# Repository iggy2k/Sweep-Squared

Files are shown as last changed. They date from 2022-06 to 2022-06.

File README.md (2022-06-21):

# Sweep Squared
 A unibody version of the Ferris Sweep split keyboard.
 
## Why?
The only reason I gave up on using the original Sweep is being able to comfortably use it on top of the laptop keyboard. Hopefully this one will work better.
upd 06/21/2022: it does actually feel better!

## But it's just Zaphod
Yes. 

## Pics
<p align="center">
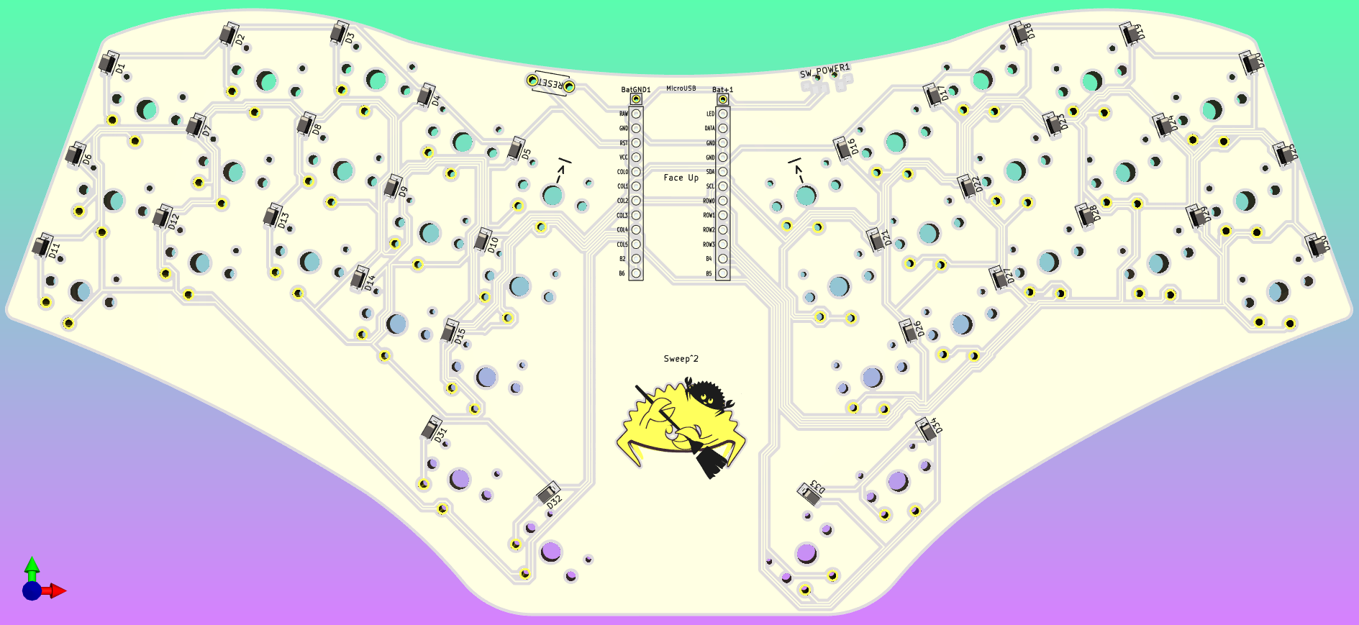
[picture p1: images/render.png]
  
</p>

## Firmware
https://github.com/iggy2k/zmk-squared
 
## Credits
Original Ferris is made by [pierrechevalier83](https://github.com/pierrechevalier83)

Ferris Sweep made by [davidphilipbarr](https://github.com/davidphilipbarr)

Symbols and footprints are credited below.

## Symbols and Footprints
Sources:

https://github.com/foostan/kbd

https://github.com/davidphilipbarr/Kicad-Footprints

https://github.com/ai03-2725/random-keyboard-parts.pretty

https://github.com/Biacco42/ProMicroKiCad

#### Also
ai03 pcb guide is super cool as well as ppl from the keeb discords.

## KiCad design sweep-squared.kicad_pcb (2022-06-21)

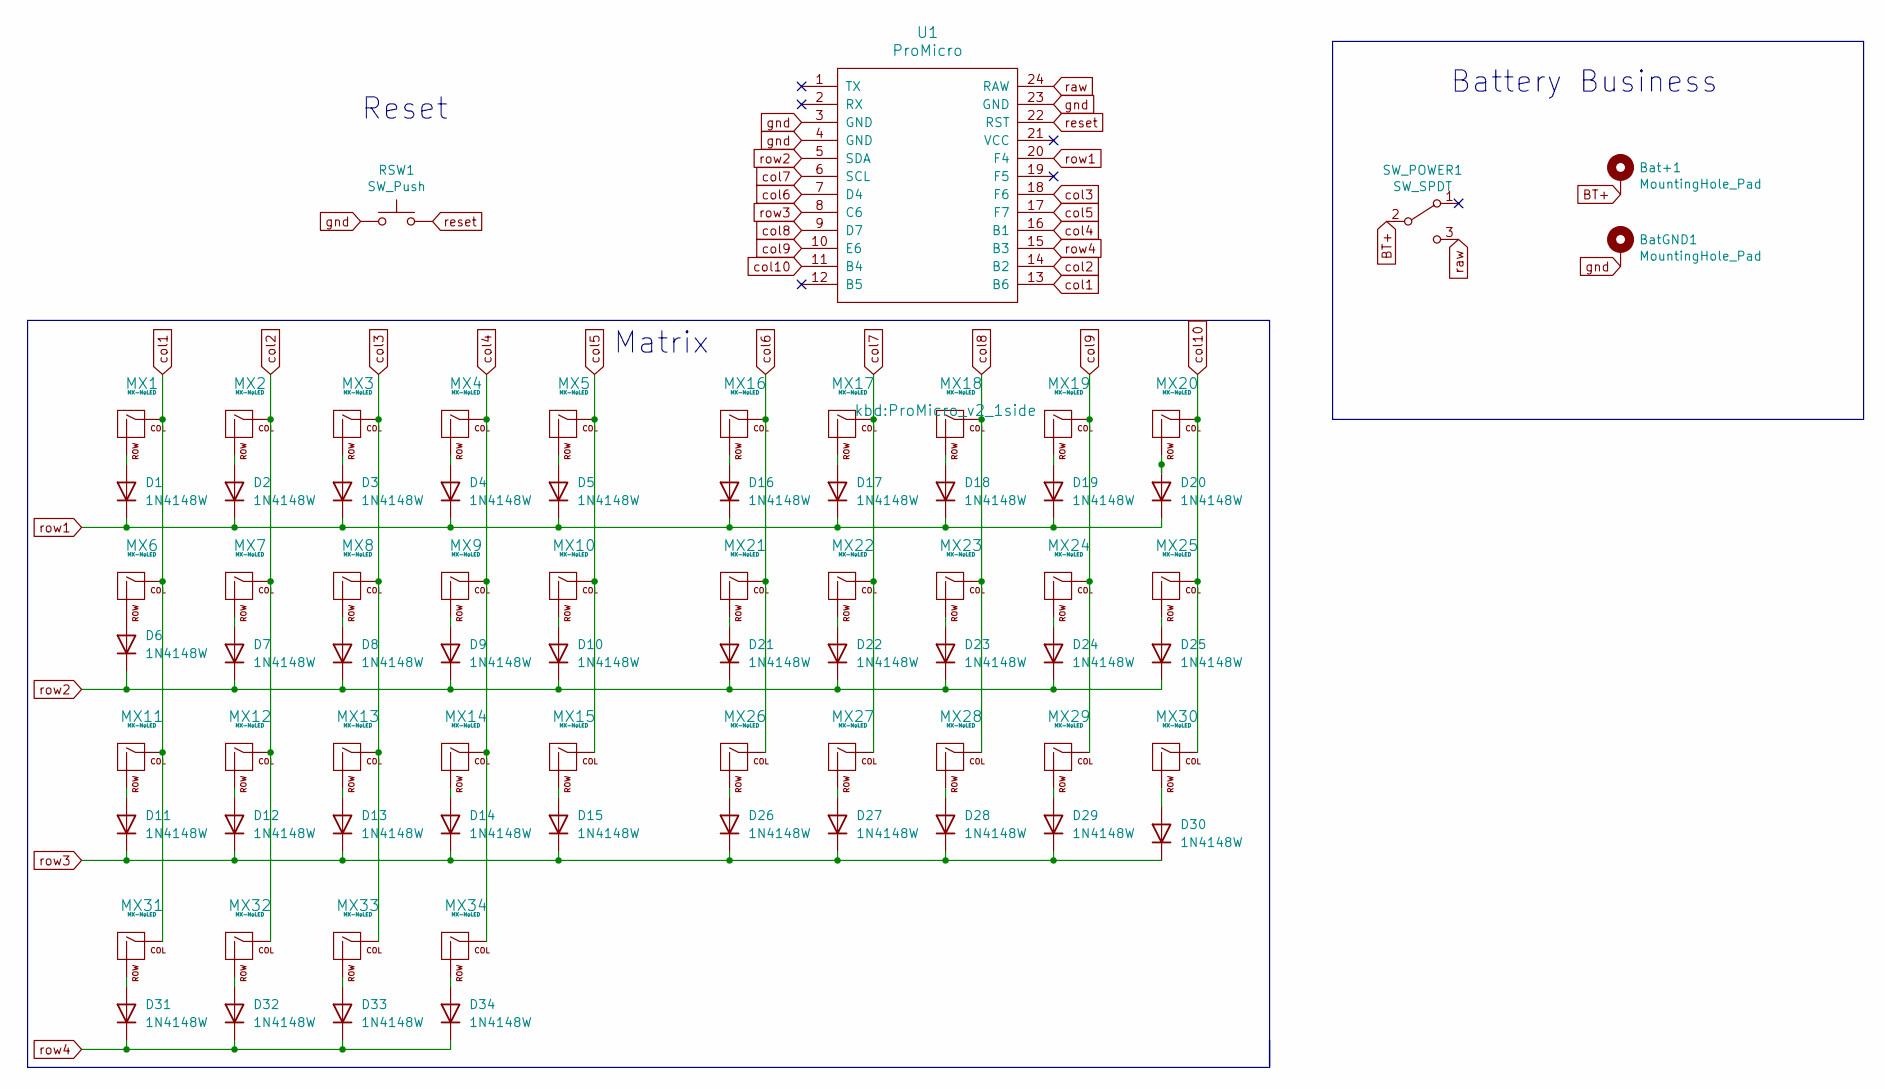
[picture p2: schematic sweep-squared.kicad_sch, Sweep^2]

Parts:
Bat+1: MountingHole_Pad; 1pin_conn
BatGND1: MountingHole_Pad; 1pin_conn
D1, D2, D3, D4, D5, D6, D7, D8, D9, D10, D11, D12, D13, D14, D15, D16, D17, D18, D19, D20, D21, D22, D23, D24, D25, D26, D27, D28, D29, D30, D31, D32, D33, D34: 1N4148W; D_SOD-123
MX1, MX2, MX3, MX4, MX5, MX6, MX7, MX8, MX9, MX10, MX11, MX12, MX13, MX14, MX15, MX16, MX17, MX18, MX19, MX20, MX21, MX22, MX23, MX24, MX25, MX26, MX27, MX28, MX29, MX30, MX31, MX32, MX33, MX34: MX-NoLED; SW_PG1350_single_b2
RSW1: SW_Push; ResetSW
SW_POWER1: SW_SPDT; SPDT_C128955
U1: ProMicro; ProMicro_v2_1side

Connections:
unnamed: Bat+1.1, SW_POWER1.2 (B)
unnamed: D1.2 (A), MX1.2 (ROW)
unnamed: D2.2 (A), MX2.2 (ROW)
unnamed: D3.2 (A), MX3.2 (ROW)
unnamed: D4.2 (A), MX4.2 (ROW)
unnamed: D5.2 (A), MX5.2 (ROW)
unnamed: D6.2 (A), MX6.2 (ROW)
unnamed: D7.2 (A), MX7.2 (ROW)
unnamed: D8.2 (A), MX8.2 (ROW)
unnamed: D9.2 (A), MX9.2 (ROW)
unnamed: D10.2 (A), MX10.2 (ROW)
unnamed: D11.2 (A), MX11.2 (ROW)
unnamed: D12.2 (A), MX12.2 (ROW)
unnamed: D13.2 (A), MX13.2 (ROW)
unnamed: D14.2 (A), MX14.2 (ROW)
unnamed: D15.2 (A), MX15.2 (ROW)
unnamed: D16.2 (A), MX16.2 (ROW)
unnamed: D17.2 (A), MX17.2 (ROW)
unnamed: D18.2 (A), MX18.2 (ROW)
unnamed: D19.2 (A), MX19.2 (ROW)
unnamed: D20.2 (A), MX20.2 (ROW)
unnamed: D21.2 (A), MX21.2 (ROW)
unnamed: D22.2 (A), MX22.2 (ROW)
unnamed: D23.2 (A), MX23.2 (ROW)
unnamed: D24.2 (A), MX24.2 (ROW)
unnamed: D25.2 (A), MX25.2 (ROW)
unnamed: D26.2 (A), MX26.2 (ROW)
unnamed: D27.2 (A), MX27.2 (ROW)
unnamed: D28.2 (A), MX28.2 (ROW)
unnamed: D29.2 (A), MX29.2 (ROW)
unnamed: D30.2 (A), MX30.2 (ROW)
unnamed: D31.2 (A), MX31.2 (ROW)
unnamed: D32.2 (A), MX32.2 (ROW)
unnamed: D33.2 (A), MX33.2 (ROW)
unnamed: D34.2 (A), MX34.2 (ROW)
col1: MX1.1 (COL), MX6.1 (COL), MX11.1 (COL), MX31.1 (COL), U1.13 (B6)
col2: MX2.1 (COL), MX7.1 (COL), MX12.1 (COL), MX32.1 (COL), U1.14 (B2)
col3: MX3.1 (COL), MX8.1 (COL), MX13.1 (COL), MX33.1 (COL), U1.18 (F6)
col4: MX4.1 (COL), MX9.1 (COL), MX14.1 (COL), MX34.1 (COL), U1.16 (B1)
col5: MX5.1 (COL), MX10.1 (COL), MX15.1 (COL), U1.17 (F7)
col6: MX16.1 (COL), MX21.1 (COL), MX26.1 (COL), U1.7 (D4)
col7: MX17.1 (COL), MX22.1 (COL), MX27.1 (COL), U1.6 (SCL)
col8: MX18.1 (COL), MX23.1 (COL), MX28.1 (COL), U1.9 (D7)
col9: MX19.1 (COL), MX24.1 (COL), MX29.1 (COL), U1.10 (E6)
col10: MX20.1 (COL), MX25.1 (COL), MX30.1 (COL), U1.11 (B4)
gnd: BatGND1.1, RSW1.1, U1.3 (GND), U1.4 (GND), U1.23 (GND); also elsewhere on the board
raw: SW_POWER1.3 (C), U1.24 (RAW); also elsewhere on the board
reset: RSW1.2, U1.22 (RST)
row1: D1.1 (K), D2.1 (K), D3.1 (K), D4.1 (K), D5.1 (K), D16.1 (K), D17.1 (K), D18.1 (K), D19.1 (K), D20.1 (K), U1.20 (F4)
row2: D6.1 (K), D7.1 (K), D8.1 (K), D9.1 (K), D10.1 (K), D21.1 (K), D22.1 (K), D23.1 (K), D24.1 (K), D25.1 (K), U1.5 (SDA)
row3: D11.1 (K), D12.1 (K), D13.1 (K), D14.1 (K), D15.1 (K), D26.1 (K), D27.1 (K), D28.1 (K), D29.1 (K), D30.1 (K), U1.8 (C6)
row4: D31.1 (K), D32.1 (K), D33.1 (K), D34.1 (K), U1.15 (B3)

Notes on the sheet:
Reset
Matrix
Battery Business

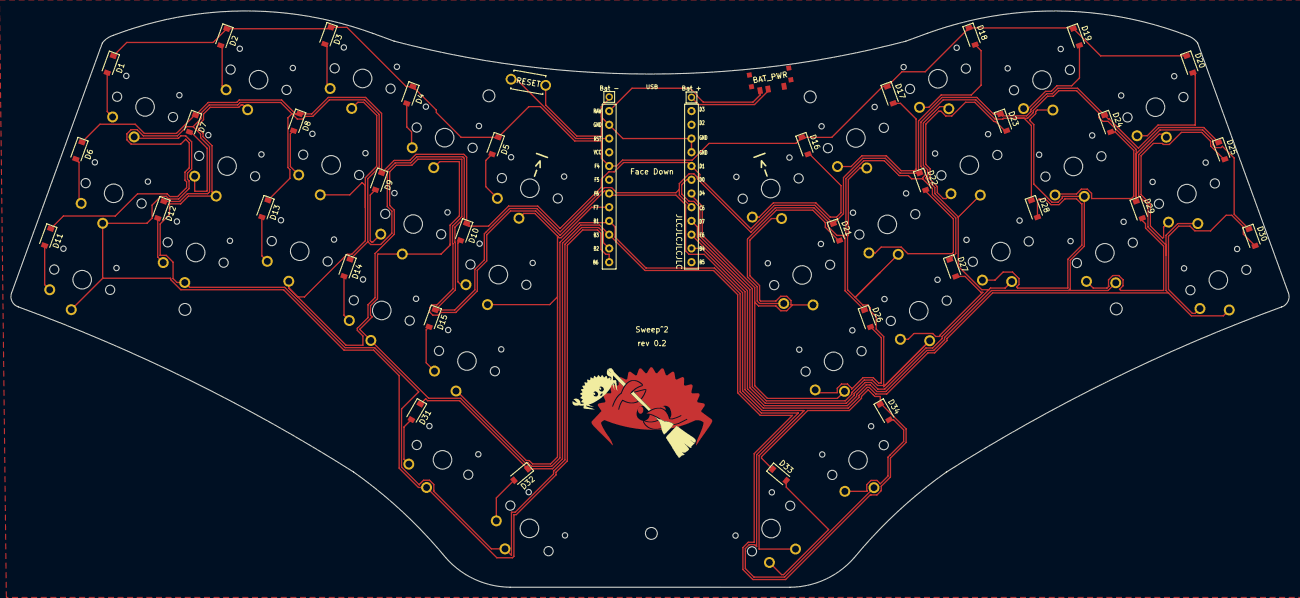
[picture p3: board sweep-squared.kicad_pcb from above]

Board: 2 copper layers, 236.3 x 106.6 mm, 73 parts (0 on the bottom side), 52 nets.

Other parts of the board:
BAT_PWR: SW_SPDT; SPDT_C128955
Bat +: MountingHole_Pad; 1pin_conn
Bat -: MountingHole_Pad; 1pin_conn

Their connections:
BT+: BAT_PWR.2 (B), Bat +.1
gnd: Bat -.1; also elsewhere on the board
raw: BAT_PWR.3 (C); also elsewhere on the board

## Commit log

2022-06-05 Finished PCB
    [sweep-squared.kicad_pcb, sweep-squared.kicad_sch]
2022-06-06 Moved thumbkeys, tilted buttons, generated gerbers
    [sweep-squared-B_Cu.gbr, sweep-squared-B_Mask.gbr, sweep-squared-B_Paste.gbr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]
2022-06-21 Rev 0.2
    Removed questionable back silkscreen
    Fixed thumb keys position (barely visible)
    Fixed bat. switch position
    Fixed many labels
    Fixed logo
    Added 5 holes for case potential
    [sweep-squared.kicad_pcb, sweep-squared.kicad_sch]
